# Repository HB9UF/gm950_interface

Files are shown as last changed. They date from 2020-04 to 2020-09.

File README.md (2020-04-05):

This is a simple interface that plugs into the back of Motorola GM950 radios to break out:

- Flat RX audio
- Flat TX audio
- The PTT line
- Open collector COS or TOS (depending on configuration)

The intended use for this project is to connect a link transceiver to the  EchoLink network. The interface was designed for the GM950 series but may also work with GM350 (untested). It was designed with KiCad 5.1.5 as a quick replacement for a failed unit. The first version was milled in-house during the COVID-19 lock-down, thus traces are extra wide and on a single layer to ease the manufacturing process.

This is provided as is under the CC BY-SA 4.0 license. In particular, no BOM is provided but the schematic is straight forward. SMD component sizes are 0805. Please refer to the schematic for modification of the suggested resistor values, depending on your application.

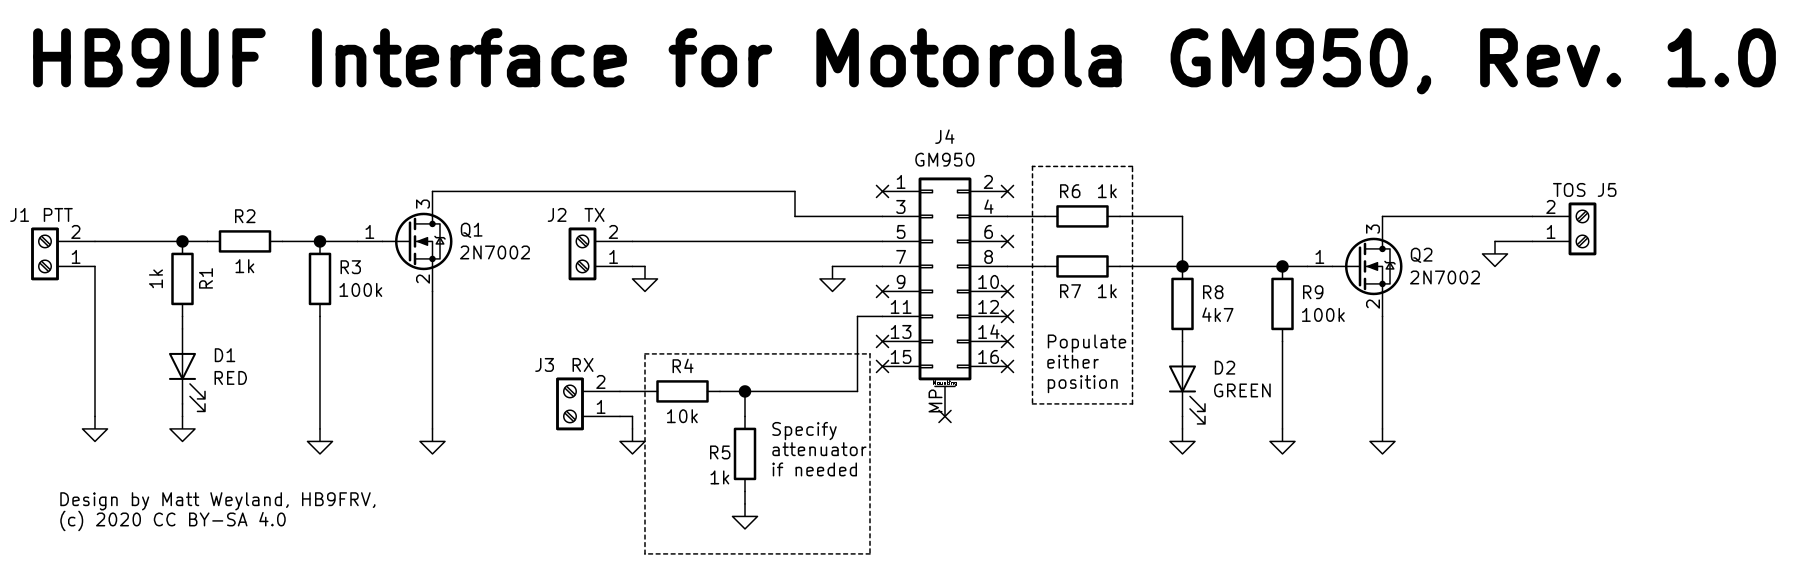
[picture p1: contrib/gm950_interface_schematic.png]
Schematic

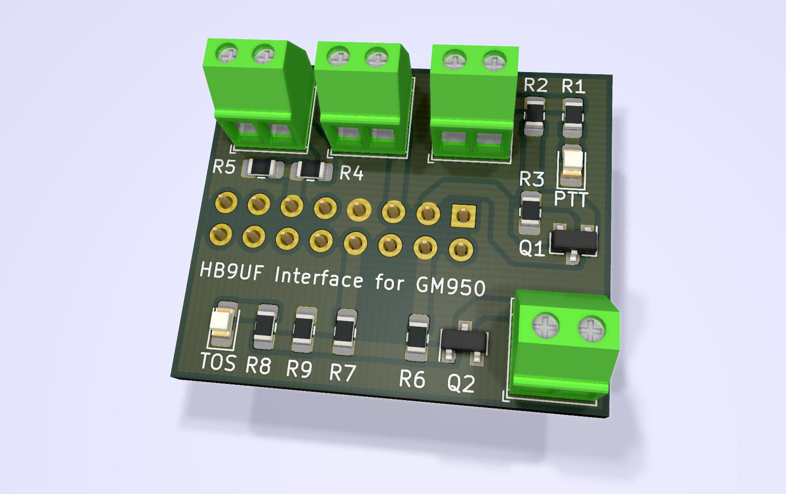
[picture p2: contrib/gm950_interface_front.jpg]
3D Rendering of front view


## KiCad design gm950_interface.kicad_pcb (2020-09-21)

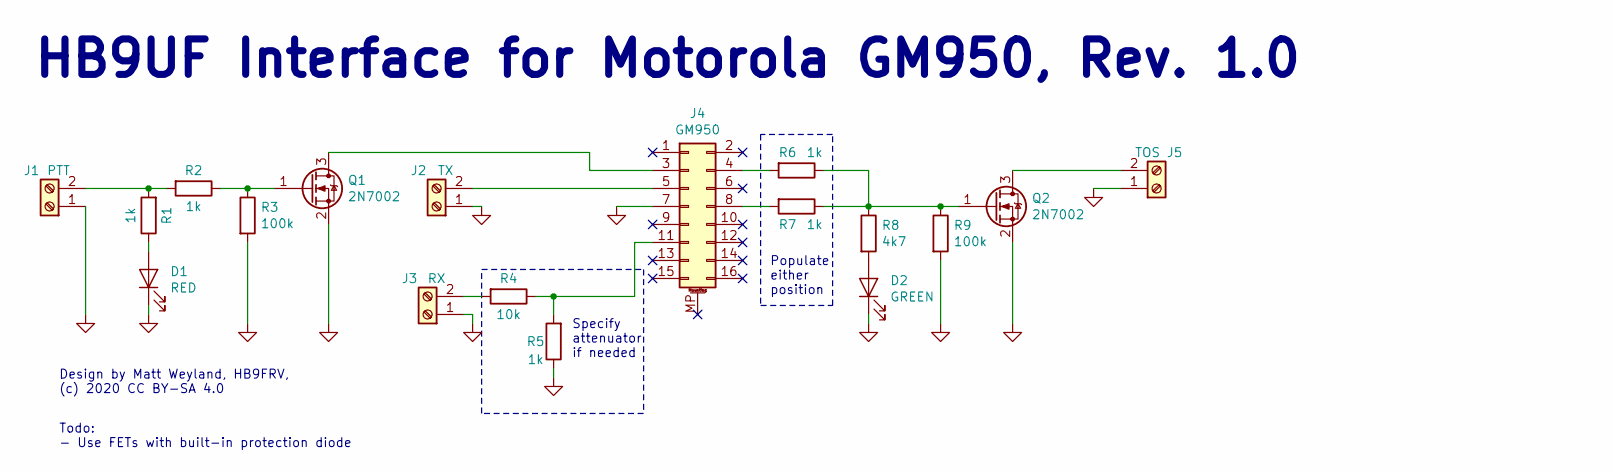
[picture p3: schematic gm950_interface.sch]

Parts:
D1: RED; LED_0805_2012Metric_Pad1.15x1.40mm_HandSolder
D2: GREEN; LED_0805_2012Metric_Pad1.15x1.40mm_HandSolder
J1: PTT; TerminalBlock_TE_282834-2_1x02_P2.54mm_Horizontal
J2: TX; TerminalBlock_TE_282834-2_1x02_P2.54mm_Horizontal
J3: RX; TerminalBlock_TE_282834-2_1x02_P2.54mm_Horizontal
J4: GM950; PinSocket_2x08_P2.54mm_Vertical
J5: TOS; TerminalBlock_TE_282834-2_1x02_P2.54mm_Horizontal
Q1, Q2: 2N7002; SOT-23
R1, R2, R5, R6, R7: 1k; R_0805_2012Metric_Pad1.15x1.40mm_HandSolder
R3, R9: 100k; R_0805_2012Metric_Pad1.15x1.40mm_HandSolder
R4: 10k; R_0805_2012Metric_Pad1.15x1.40mm_HandSolder
R8: 4k7; R_0805_2012Metric_Pad1.15x1.40mm_HandSolder

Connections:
GND: D1.1 (K), D2.1 (K), J1.1, J2.1, J3.1, J4.7, J5.1, Q1.2 (S), Q2.2 (S), R3.2, R5.1, R9.2
unnamed: D1.2 (A), R1.1
unnamed: D2.2 (A), R8.2
unnamed: J1.2, R1.2, R2.2
unnamed: J2.2, J4.5
unnamed: J3.2, R4.2
unnamed: J4.3, Q1.3 (D)
unnamed: J4.4, R6.2
unnamed: J4.8, R7.2
unnamed: J4.11, R4.1, R5.2
unnamed: J5.2, Q2.3 (D)
unnamed: Q1.1 (G), R2.1, R3.1
unnamed: Q2.1 (G), R6.1, R7.1, R8.1, R9.1

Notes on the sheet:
Todo: - Use FETs with built-in protection diode
Design by Matt Weyland, HB9FRV, (c) 2020 CC BY-SA 4.0
HB9UF Interface for Motorola GM950, Rev. 1.0
Specify attenuator if needed
Populate either position

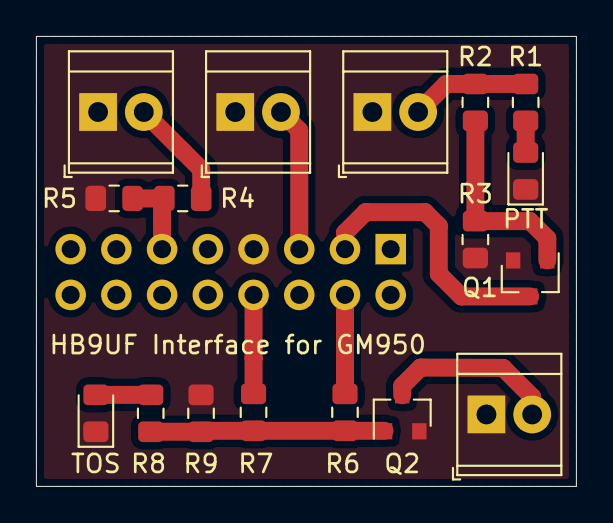
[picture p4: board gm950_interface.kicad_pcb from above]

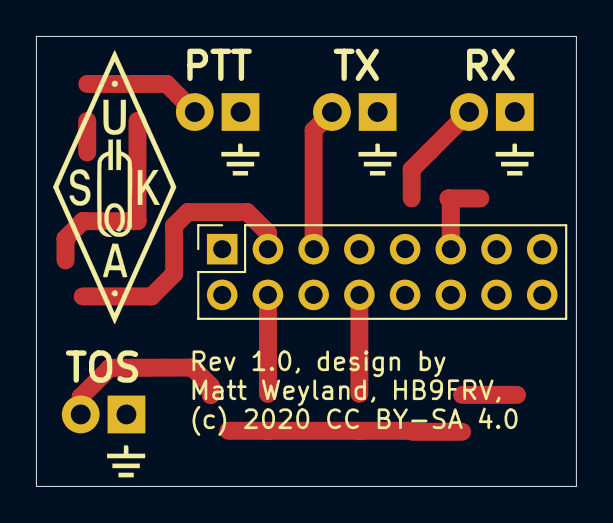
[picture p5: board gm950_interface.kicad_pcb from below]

Board: 2 copper layers, 30.0 x 25.0 mm, 22 parts (5 on the bottom side), 13 nets.

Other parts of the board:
VAL: GND
VAL#2, VAL#3, VAL#4: GND

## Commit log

2020-04-05 Initial commit of rev. 1.0
    [gm950_interface.kicad_pcb, gm950_interface.sch]
2020-04-05 Adding .gitignore file for KiCad projects.
2020-04-05 Adding images of schematic and rendering of PCB, included in README.md file
2020-09-21 Bumping KiCad version number. This is the Rev. 1.0 release.
    [gm950_interface.kicad_pcb]
